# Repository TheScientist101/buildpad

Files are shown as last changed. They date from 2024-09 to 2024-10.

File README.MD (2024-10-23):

# Buildpad

This is my first time working on any hardware-ish stuff. This took me way longer than it should have because there are many versions that I scrapped (I didn't even push) and because I had to learn how to use KiCad and Fusion360. I initially planned on having two rotary encoders but I decided that IO expansion was a little too difficult to deal with especially to be within the size constraint and without SMD parts (since I am not comfortable soldering them). I also wanted to have Neopixels for the underglow but that never ended up happening because I designed a solution and later realized the need for resistors and decoupling capacitors which I tried adding, but I also later decided that I did not want to solder SMD components. My best solution to still get the RGB effect I wanted was to use these color changing LEDs in my BOM below.

# BOM:

- 16x Gateron Milky Yellow Switches (or any other switch)
- 16x Through-hole 1N4148 Diodes
- 16x Slow Fading RGB LEDs (234-RGB-Slow at https://www.aliexpress.com/item/1005005310058942.html) (3.0-3.4V, 20mA)
- 1x Bottom of the Case 3D Printed in Yellow Filament (if available or just the closest available color)
- 1x Top of the Case 3D Printed in Yellow Filament (if available or just the closest available color)
- 4x 3D Printed Screws in Black Filament (if available or just the closest available color)
- 16x Blank Red Keycaps (1u size)
- 1x 0.91 inch OLED Display (128x32) SSD1306
- 1x Xiao Seed RP2040
- 1x PCB

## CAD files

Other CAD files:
cad/Hackpad Case.f3d

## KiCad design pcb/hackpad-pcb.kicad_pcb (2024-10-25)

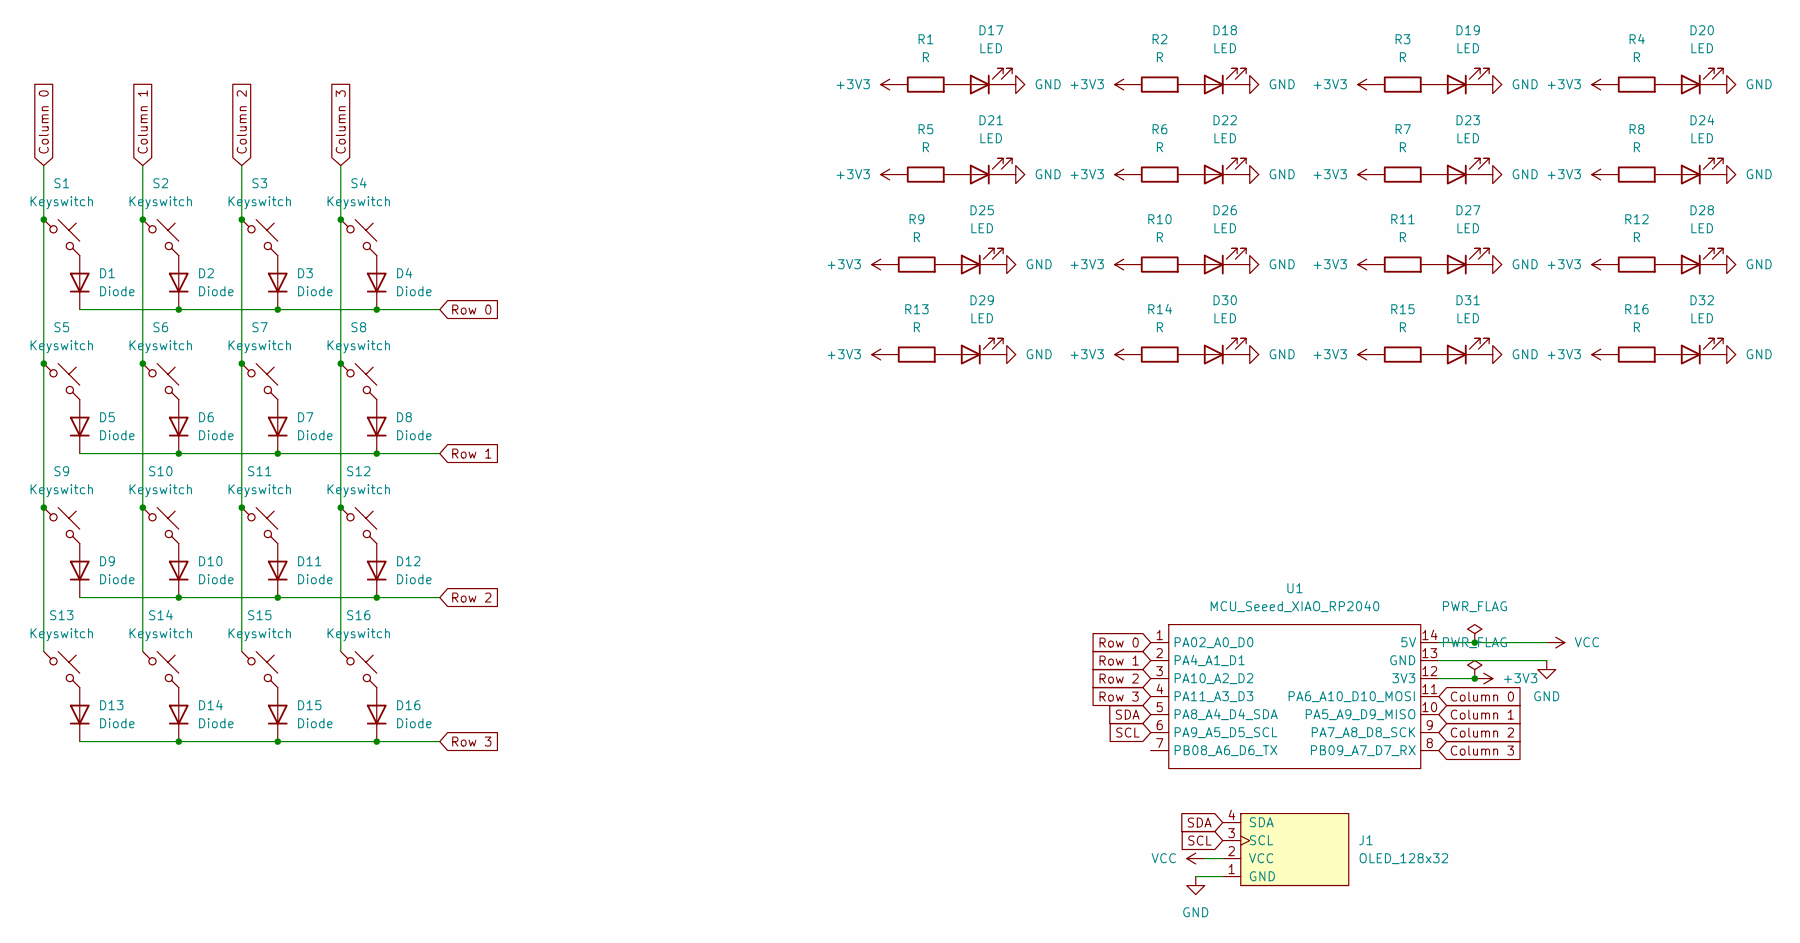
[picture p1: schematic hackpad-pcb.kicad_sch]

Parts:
D1, D2, D3, D4, D5, D6, D7, D8, D9, D10, D11, D12, D13, D14, D15, D16: Diode; Diode_DO-35
D17, D18, D19, D20, D21, D22, D23, D24, D25, D26, D27, D28, D29, D30, D31, D32: LED; LED_MX_3mm-ROT
J1: OLED_128x32
R1, R2, R3, R4, R5, R6, R7, R8, R9, R10, R11, R12, R13, R14, R15, R16: R; R_Axial_DIN0207_L6.3mm_D2.5mm_P7.62mm_Horizontal
S1, S2, S3, S4, S5, S6, S7, S8, S9, S10, S11, S12, S13, S14, S15, S16: Keyswitch; MX_Plate_1.00u
U1: MCU_Seeed_XIAO_RP2040; Seeed_XIAO_RP2040

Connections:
+3V3: R1.1, R2.1, R3.1, R4.1, R5.1, R6.1, R7.1, R8.1, R9.1, R10.1, R11.1, R12.1, R13.1, R14.1, R15.1, R16.1, U1.12 (3V3)
Column 0: S1.1, S5.1, S9.1, S13.1, U1.11 (PA6_A10_D10_MOSI)
Column 1: S2.1, S6.1, S10.1, S14.1, U1.10 (PA5_A9_D9_MISO)
Column 2: S3.1, S7.1, S11.1, S15.1, U1.9 (PA7_A8_D8_SCK)
Column 3: S4.1, S8.1, S12.1, S16.1, U1.8 (PB09_A7_D7_RX)
GND: D17.1 (K), D18.1 (K), D19.1 (K), D20.1 (K), D21.1 (K), D22.1 (K), D23.1 (K), D24.1 (K), D25.1 (K), D26.1 (K), D27.1 (K), D28.1 (K), D29.1 (K), D30.1 (K), D31.1 (K), D32.1 (K), J1.1 (GND), U1.13 (GND)
unnamed: D1.2 (A), S1.2
unnamed: D2.2 (A), S2.2
unnamed: D3.2 (A), S3.2
unnamed: D4.2 (A), S4.2
unnamed: D5.2 (A), S5.2
unnamed: D6.2 (A), S6.2
unnamed: D7.2 (A), S7.2
unnamed: D8.2 (A), S8.2
unnamed: D9.2 (A), S9.2
unnamed: D10.2 (A), S10.2
unnamed: D11.2 (A), S11.2
unnamed: D12.2 (A), S12.2
unnamed: D13.2 (A), S13.2
unnamed: D14.2 (A), S14.2
unnamed: D15.2 (A), S15.2
unnamed: D16.2 (A), S16.2
unnamed: D17.2 (A), R1.2
unnamed: D18.2 (A), R2.2
unnamed: D19.2 (A), R3.2
unnamed: D20.2 (A), R4.2
unnamed: D21.2 (A), R5.2
unnamed: D22.2 (A), R6.2
unnamed: D23.2 (A), R7.2
unnamed: D24.2 (A), R8.2
unnamed: D25.2 (A), R9.2
unnamed: D26.2 (A), R10.2
unnamed: D27.2 (A), R11.2
unnamed: D28.2 (A), R12.2
unnamed: D29.2 (A), R13.2
unnamed: D30.2 (A), R14.2
unnamed: D31.2 (A), R15.2
unnamed: D32.2 (A), R16.2
Row 0: D1.1 (K), D2.1 (K), D3.1 (K), D4.1 (K), U1.1 (PA02_A0_D0)
Row 1: D5.1 (K), D6.1 (K), D7.1 (K), D8.1 (K), U1.2 (PA4_A1_D1)
Row 2: D9.1 (K), D10.1 (K), D11.1 (K), D12.1 (K), U1.3 (PA10_A2_D2)
Row 3: D13.1 (K), D14.1 (K), D15.1 (K), D16.1 (K), U1.4 (PA11_A3_D3)
SCL: J1.3 (SCL), U1.6 (PA9_A5_D5_SCL)
SDA: J1.4 (SDA), U1.5 (PA8_A4_D4_SDA)
VCC: J1.2 (VCC), U1.14 (5V)

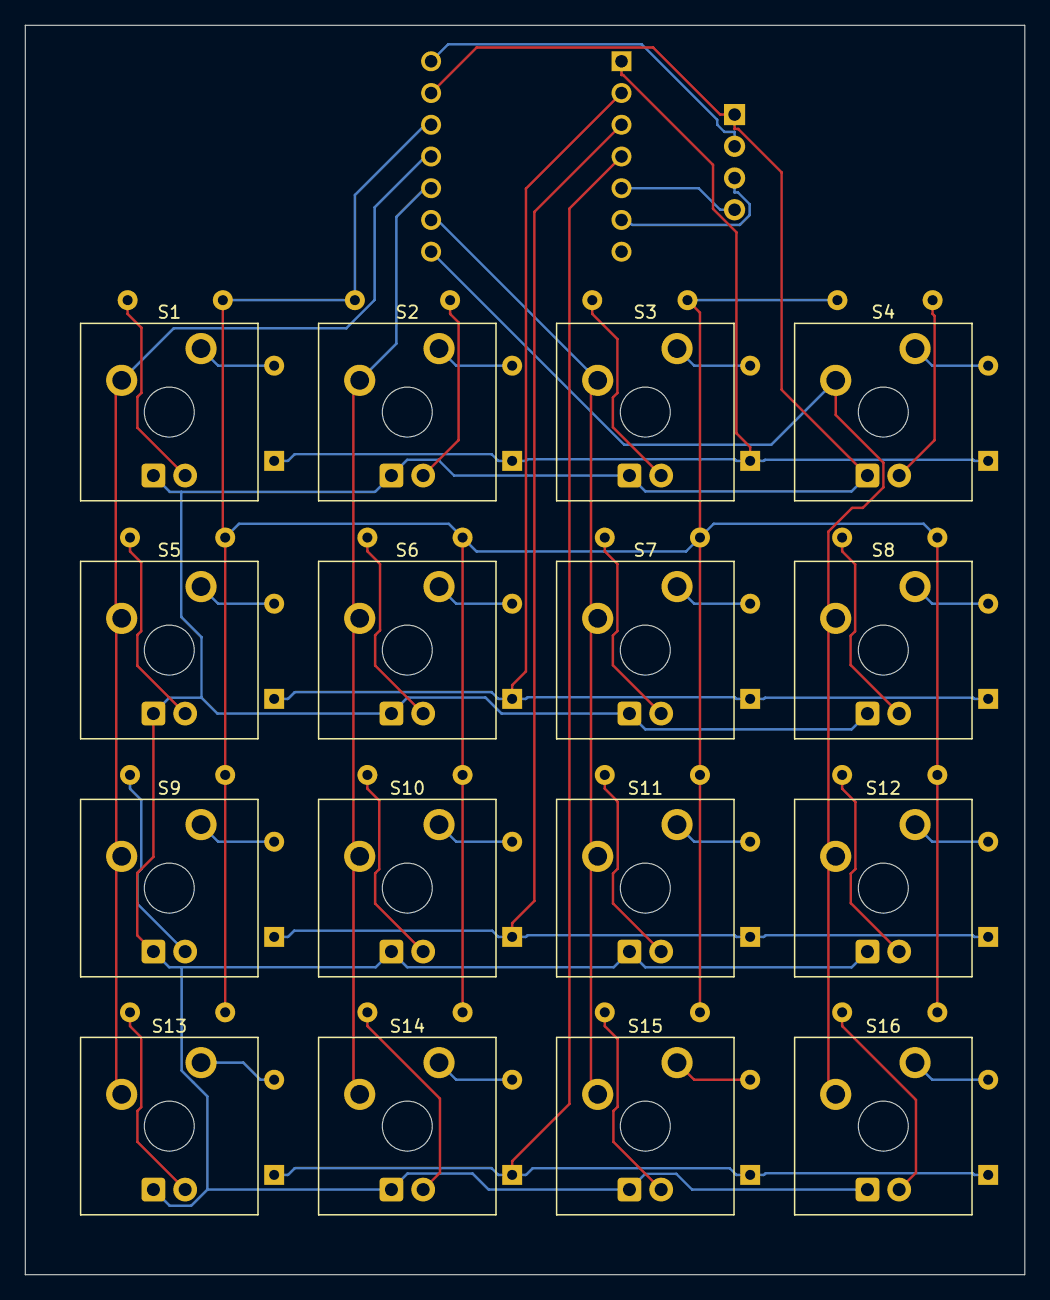
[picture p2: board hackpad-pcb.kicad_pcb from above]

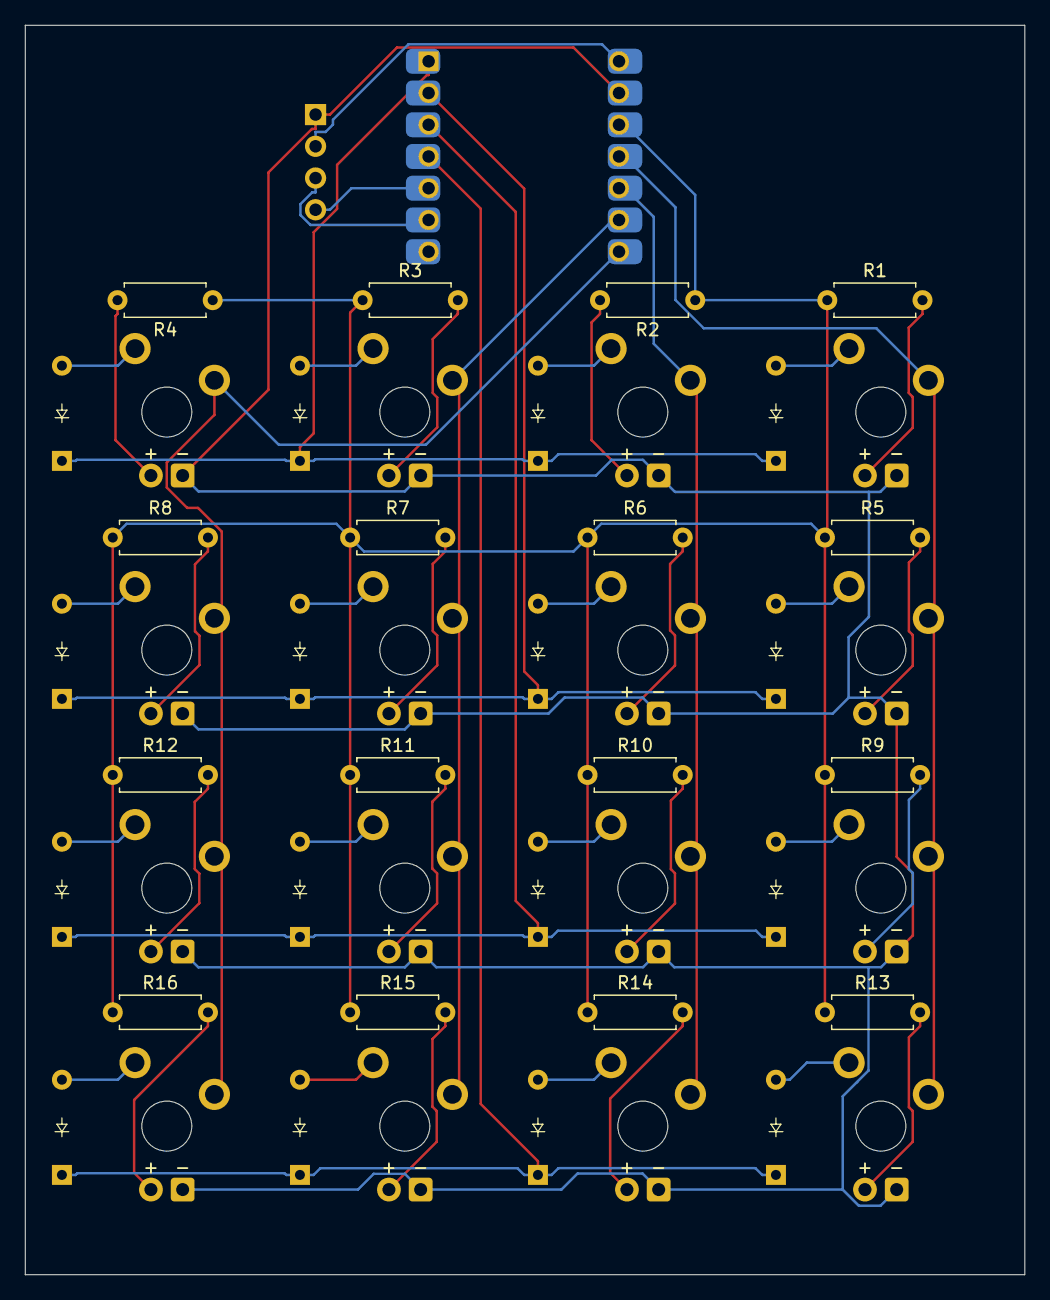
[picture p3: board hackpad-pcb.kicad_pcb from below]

Board: 2 copper layers, 80.0 x 100.0 mm, 66 parts (33 on the bottom side), 45 nets.

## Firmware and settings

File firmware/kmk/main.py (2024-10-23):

import board
from kmk.kmk_keyboard import KMKKeyboard
from kmk.keys import KC
from kmk.scanners import DiodeOrientation
from kmk.extensions.display import Display, TextEntry, ImageEntry
from kmk.extensions.display.ssd1306 import SSD1306
import busio

BUS = busio.I2C(board.GP_SCL, board.GP_SDA)

driver = SSD1306(i2c=BUS, device_address=0x3C)

display = Display(
    display=driver,
    width=128,
    height=32
)

display.entries = [
    TextEntry("Hello, World!"),
    ImageEntry("kmk_logo.pbm"),
]

keyboard = KMKKeyboard()

keyboard.col_pins = (board.GP3, board.GP4, board.GP2, board.GP1)
keyboard.row_pins = (board.GP26, board.GP27, board.GP28, board.GP29)
keyboard.diode_orientation = DiodeOrientation.COL2ROW

# I'm going to change this as I see fit when I get it physically
keyboard.keymap = [
    [
        [KC.MUTE, KC.VOLD, KC.VOLU, KC.PLAY_PAUSE],  # Media controls
        [KC.SCRN, KC.NEW_TAB, KC.WEB_SEARCH, KC.FIND],  # Productivity shortcuts
        [KC.COPY, KC.PASTE, KC.CUT, KC.UNDO],        # Editing shortcuts
        [KC.LCTRL, KC.LALT, KC.LSFT, KC.SPC],       # Modifier keys and space
    ],
]

if __name__ == '__main__':
    keyboard.go()

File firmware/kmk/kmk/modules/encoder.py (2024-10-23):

# See docs/encoder.md for how to use

import busio
import digitalio
from supervisor import ticks_ms

from kmk.modules import Module

# NB : not using rotaryio as it requires the pins to be consecutive


class BaseEncoder:

    VELOCITY_MODE = True

    def __init__(self, is_inverted=False, divisor=4):

        self.is_inverted = is_inverted
        self.divisor = divisor

        self._state = None
        self._start_state = None
        self._direction = None
        self._pos = 0
        self._button_state = True
        self._button_held = None
        self._velocity = 0

        self._movement = 0
        self._timestamp = ticks_ms()

        # callback functions on events. Need to be defined externally
        self.on_move_do = None
        self.on_button_do = None

    def get_state(self):
        return {
            'direction': self.is_inverted and -self._direction or self._direction,
            'position': self.is_inverted and -self._pos or self._pos,
            'is_pressed': not self._button_state,
            'velocity': self._velocity,
        }

        # Called in a loop to refresh encoder state

    def update_state(self):
        # Rotation events
        new_state = (self.pin_a.get_value(), self.pin_b.get_value())

        if new_state != self._state:
            # encoder moved
            self._movement += 1
            # false / false and true / true are common half steps
            # looking on the step just before helps determining
            # the direction
            if new_state[0] == new_state[1] and self._state[0] != self._state[1]:
                if new_state[1] == self._state[0]:
                    self._direction = 1
                else:
                    self._direction = -1

            # when the encoder settles on a position (every 2 steps)
            if new_state[0] == new_state[1]:
                # an encoder returned to the previous
                # position halfway, cancel rotation
                if (
                    self._start_state[0] == new_state[0]
                    and self._start_state[1] == new_state[1]
                    and self._movement <= 2
                ):
                    self._movement = 0
                    self._direction = 0

                # when the encoder made a full loop according to its divisor
                elif self._movement >= self.divisor - 1:
                    # 1 full step is 4 movements (2 for high-resolution encoder),
                    # however, when rotated quickly, some steps may be missed.
                    # This makes it behave more naturally
                    real_movement = self._movement // self.divisor
                    self._pos += self._direction * real_movement
                    if self.on_move_do is not None:
                        for i in range(real_movement):
                            self.on_move_do(self.get_state())

                    # Rotation finished, reset to identify new movement
                    self._movement = 0
                    self._direction = 0
                    self._start_state = new_state

            self._state = new_state

        # Velocity
        self.velocity_event()

        # Button event
        self.button_event()

    def velocity_event(self):
        if self.VELOCITY_MODE:
            new_timestamp = ticks_ms()
            self._velocity = new_timestamp - self._timestamp
            self._timestamp = new_timestamp

    def button_event(self):
        raise NotImplementedError('subclasses must override button_event()!')

    # return knob velocity as milliseconds between position changes (detents)
    # for backwards compatibility
    def vel_report(self):
        # print(self._velocity)
        return self._velocity


class GPIOEncoder(BaseEncoder):
    def __init__(
        self,
        pin_a,
        pin_b,
        pin_button=None,
        is_inverted=False,
        divisor=None,
        button_pull=digitalio.Pull.UP,
    ):
        super().__init__(is_inverted)

        # Divisor can be 4 or 2 depending on whether the detent
        # on the encoder is defined by 2 or 4 pulses
        self.divisor = divisor

        self.pin_a = EncoderPin(pin_a)
        self.pin_b = EncoderPin(pin_b)
        if pin_button:
            self.pin_button = EncoderPin(pin_button, button_type=True, pull=button_pull)
        else:
            self.pin_button = None

        self._state = (self.pin_a.get_value(), self.pin_b.get_value())
        self._start_state = self._state

    def button_event(self):
        if self.pin_button:
            new_button_state = self.pin_button.get_value()
            if new_button_state != self._button_state:
                self._button_state = new_button_state
                if self.on_button_do is not None:
                    self.on_button_do(self.get_state())


class EncoderPin:
    def __init__(self, pin, button_type=False, pull=digitalio.Pull.UP):
        self.pin = pin
        self.button_type = button_type
        self.pull = pull
        self.prepare_pin()

    def prepare_pin(self):
        if self.pin is not None:
            if isinstance(self.pin, digitalio.DigitalInOut):
                self.io = self.pin
            else:
                self.io = digitalio.DigitalInOut(self.pin)
            self.io.direction = digitalio.Direction.INPUT
            self.io.pull = self.pull
        else:
            self.io = None

    def get_value(self):
        io = self.io
        result = io.value
        if digitalio.Pull.UP != io.pull:
            result = not result
        return result
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

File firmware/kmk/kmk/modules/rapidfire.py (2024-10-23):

from micropython import const

from random import randint

from kmk.keys import Key, make_argumented_key
from kmk.modules import Module
from kmk.utils import Debug

debug = Debug(__name__)

_INACTIVE = const(0)
_HOLD = const(1)
_ACTIVE = const(2)


class RapidFireKey(Key):
    def __init__(
        self,
        key,
        interval=100,
        timeout=200,
        enable_interval_randomization=False,
        randomization_magnitude=15,
        toggle=False,
        **kwargs,
    ):
        super().__init__(**kwargs)
        self.key = key
        self.interval = interval
        self.timeout = timeout
        self.enable_interval_randomization = enable_interval_randomization
        self.randomization_magnitude = randomization_magnitude
        self.toggle = toggle
        self._state = _INACTIVE
        self._timeout = None


class RapidFire(Module):
    def __init__(self):
        make_argumented_key(
            names=('RF',),
            constructor=RapidFireKey,
            on_press=self._rf_pressed,
            on_release=self._rf_released,
        )

    def _on_timer_timeout(self, key, keyboard):
        if key._state == _HOLD:
            key._state = _ACTIVE
            keyboard.remove_key(key.key)
            key._timeout = keyboard.set_timeout(
                1, lambda: self._on_timer_timeout(key, keyboard)
            )
            return

        keyboard.add_key(key.key)
        keyboard.set_timeout(1, lambda: keyboard.remove_key(key.key))

        interval = key.interval
        if key.enable_interval_randomization:
            interval += randint(
                -key.randomization_magnitude, key.randomization_magnitude
            )
        key._timeout = keyboard.set_timeout(
            interval, lambda: self._on_timer_timeout(key, keyboard)
        )

        if debug.enabled:
            debug(key.key, ' @', interval, 'ms')

    def _rf_pressed(self, key, keyboard, *args, **kwargs):
        if key._state == _ACTIVE:
            self._deactivate_key(key, keyboard)
            return

        keyboard.add_key(key.key)
        key._state = _HOLD
        key._timeout = keyboard.set_timeout(
            key.timeout, lambda: self._on_timer_timeout(key, keyboard)
        )

    def _rf_released(self, key, keyboard, *args, **kwargs):
        if key._state == _ACTIVE:
            if key.toggle:
                return
            key._state = _INACTIVE
        elif key._state == _INACTIVE:
            return
        else:
            keyboard.remove_key(key.key)

        self._deactivate_key(key, keyboard)

    def _deactivate_key(self, key, keyboard):
        keyboard.cancel_timeout(key._timeout)
        key._state = _INACTIVE
        key._timeout = None

    def during_bootup(self, keyboard):
        return

    def before_matrix_scan(self, keyboard):
        return

    def before_hid_send(self, keyboard):
        return

    def after_hid_send(self, keyboard):
        return

    def on_powersave_enable(self, keyboard):
        return

    def on_powersave_disable(self, keyboard):
        return

    def after_matrix_scan(self, keyboard):
        return

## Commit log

2024-09-27 add footprint libraries
2024-09-28 Made schematic and routed wires
    [hackpad-pcb.kicad_pcb, hackpad-pcb.kicad_sch]
2024-09-28 Moved diodes and added OLED
    [hackpad-pcb.kicad_pcb, hackpad-pcb.kicad_sch]
2024-09-30 Routed a little bit more
    [hackpad-pcb.kicad_pcb, hackpad-pcb.kicad_sch]
2024-10-21 Replaced neopixels with simple 2x3x4 mm leds to avoid smd soldering
    [hackpad-pcb.kicad_pcb, hackpad-pcb.kicad_sch]
2024-10-21 Routed pcb using freerouter
    [hackpad-pcb.kicad_pcb]
2024-10-22 Completed case CAD
    [Hackpad Case.f3d]
2024-10-23 Added keycaps to CAD and made firmware using kmk
    [Hackpad Case.f3d]
2024-10-23 Resized pcb and updated model
    [hackpad-pcb.kicad_pcb]
2024-10-24 Changed local label to global label
    [hackpad-pcb.kicad_sch]
2024-10-25 Add resistors for LEDs
    [hackpad-pcb.kicad_pcb, hackpad-pcb.kicad_sch]
